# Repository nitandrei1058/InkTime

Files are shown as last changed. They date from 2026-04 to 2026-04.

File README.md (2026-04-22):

# InkTime - Smartwatch Open Source

## Diagrama Bloc

```mermaid
graph TD
    subgraph Power Management
        J4[USB-C Connector] -->|VBUS| D3[USBLC6-2SC6Y ESD]
        D3 --> IC1[BQ25180 LiPo Charger]
        BATT[LiPo Battery 250mAh] <--> IC1
        BATT --> U3[MAX17048 Fuel Gauge]
        IC1 -->|VSYS| IC9[RT6160A DC-DC Buck-Boost]
        IC9 -->|3.3V| VDD_SYS[System 3.3V]
    end

    subgraph Microcontroller
        U1[nRF52840 SoC]
        VDD_SYS --> U1
        U1 <-->|SWD| J2[TC2030 Debug]
        U1 <-->|RF| ANT[2.4GHz Antenna]
    end

    subgraph Peripherals
        U1 -->|I2C| IC3[BMA421 IMU]
        U1 -->|I2C| U3
        U1 -->|I2C| IC2[DRV2605L Haptic]
        U1 -->|I2C| IC1
        IC2 --> MOTOR[Vibration Motor]
        U1 -->|SPI + GPIO| J1["EPD Display 1.54 inch"]
        U1 -->|GPIO| BTN[3x Tactile Buttons]
    end
```

## Bill of Materials (BOM)

| Referință | Componentă | Valoare / Pachet | Datasheet | Link JLCParts / Procurare |
|:---|:---|:---|:---|:---|
| **U1** | Nordic nRF52840 | nRF52840-QIAA (QFN-73) | [Datasheet](https://infocenter.nordicsemi.com/pdf/nRF52840_PS_v1.7.pdf) | [C190794](https://jlcpcb.com/partdetail/NordicSemiconductor-nRF52840QIAA/C190794) |
| **IC1** | TI BQ25180 | LiPo Charger (DSBGA-8) | [Datasheet](https://www.ti.com/lit/ds/symlink/bq25180.pdf) | [C3682423](https://jlcpcb.com/partdetail/TexasInstruments-BQ25180YBGR/C3682423) |
| **IC9** | Richtek RT6160A | DC-DC Buck-Boost 3.3V | [Datasheet](https://www.richtek.com/assets/product_file/RT6160A/DS6160A-00.pdf) | [C7065276](https://jlcpcb.com/partdetail/RichtekTech-RT6160AWSC/C7065276) |
| **U3** | Analog MAX17048 | Fuel Gauge (TDFN-8) | [Datasheet](https://www.analog.com/media/en/technical-documentation/data-sheets/MAX17048-MAX17049.pdf) | [C2682616](https://jlcpcb.com/partdetail/2777647-MAX17048GT10/C2682616) |
| **IC3** | Bosch BMA421 | Accelerometru (LGA-12) | [Datasheet](https://www.bosch-sensortec.com/media/boschsensortec/downloads/datasheets/bst-bma423-ds000.pdf) | [C5242966](https://jlcpcb.com/partdetail/BoschSensortec-BMA423/C189517) |
| **IC2** | TI DRV2605L | Haptic Driver (DSBGA) | [Datasheet](https://www.ti.com/lit/ds/symlink/drv2605.pdf) | [C527464](https://jlcpcb.com/partdetail/TexasInstruments-DRV2605YZFR/C81079) |
| **D3** | ST USBLC6-2SC6Y | USB ESD (SOT-23-6) | [Datasheet](https://www.st.com/resource/en/datasheet/usblc6-2.pdf) | [C2969755](https://jlcpcb.com/partdetail/STMicroelectronics-USBLC62SC6Y/C2969755) |
| **J4** | KH-TYPE-C-16P | USB-C 16-pin | - | [C709357](https://jlcpcb.com/partdetail/Shenzhen_KinghelmElec-KH_TYPE_C16P/C709357) |
| **J1** | Molex 503480-2400 | FPC 24-pin pt EPD | [Datasheet](https://www.molex.com/en-us/products/part-detail/503480-2400) | [C122434](https://jlcpcb.com/partdetail/MOLEX-5034802400/C122434) |
| **J2** | TC2030-IDC | SWD Tag-Connect | [Datasheet](https://www.tag-connect.com/product/tc2030-idc-nl) | - |
| **ANT1**| Johanson 2450AT18 | Antenă 2.4GHz | [Datasheet](https://www.johansontechnology.com/datasheets/2450AT18B100E/2450AT18B100E.pdf)| [C2917717](https://jlcpcb.com/partdetail/JohansonDielectrics-2450AT18B100E/C2917717) |
| **X1** | 32MHz | Oscilator HFXO | - | [C383840](https://jlcpcb.com/partdetail/357112-X201632MMB4SI/C383840) |
| **X2** | 32.768kHz | Oscilator LFXO | - | [C32346](https://jlcpcb.com/partdetail/SeikoEpson-Q13FC13500004/C32346) |
| **SW1-3**| EVP-AKE31A | Butoane tactile | [Datasheet](https://industrial.panasonic.com/cdbs/www-data/pdf/ATV0000/ATV0000CE5.pdf) | [C136814](https://jlcpcb.com/parts/componentSearch?searchTxt=EVP-AKE31A) |
| **Q1** | DMG2305UX / AO3401A| P-MOSFET EPD Power | [Datasheet](https://www.diodes.com/assets/Datasheets/DMG2305UX.pdf) | [C15127](https://jlcpcb.com/partdetail/Alpha_OmegaSemicon-AO3401A/C15127) |
| **Q3** | SI1308EDL | N-MOSFET EPD Boost | [Datasheet](https://www.vishay.com/docs/73217/si1308edl.pdf) | [C469327](https://jlcpcb.com/partdetail/VishayIntertech-SI1308EDL_T1GE3/C469327) |
| **-** | AKYGA LP502030 | Baterie LiPo 3.7V / 250mAh | [Datasheet](https://www.tme.eu/Document/b9e12bf26ad0ba929a22ab5d58f022cd/AKY0106.pdf) | Extern |
| **-** | Waveshare 1.54" | Display EPD 200x200 | [Datasheet](https://www.tme.eu/Document/0ca57a8ffbcd57b5bca53252eb9d6ec3/WSH-12561.pdf) | Extern |
| **-** | FIT0774 | Motor Vibrații 10x2.7mm | - | Extern |

*(Notă: Inductoarele de boost/RF/Buck, diodele MBR0530, rezistențele și condensatorii SMD se regăsesc enumerate complet în fișierul `.bom` și `.csv` atașate la proiect).*

## Funcționalitate Hardware

Arhitectura InkTime a fost gândită în primul rând pentru **gestionarea eficientă a consumului de energie** și miniaturizare. Am folosit un proces de asamblare pe o singură parte a plăcii (TOP) și o grosime a PCB-ului de **1mm**.

### 1. Modulul de Procesare & RF
Microcontrollerul central este **Nordic nRF52840 (QFN-73)**, ideal datorită capabilităților extinse, integrarea Bluetooth 5 Low Energy și consum redus. Placa include o antenă de 2.4GHz tip chip (Johanson) conectată la o rețea de adaptare a impedanței formată din condensatori și inductoare minime. Zona de sub antenă respectă o restricție strictă (keepout pe planul de masă) pe ambele straturi pentru a asigura transmisia RF adecvată. Mufa USB-C folosește direct controllerul USB nativ din MCU și este protejată contra descărcărilor electrostatice (ESD) prin componenta D3 (USBLC6).

### 2. Power Management & Încărcare (PMIC)
Sistemul utilizează următoarele blocuri:
*   **BQ25180 (IC1):** Se ocupă de încărcarea celulei LiPo din VBUS (USB-C). Permite configurare hardware via I2C și generează rail-ul de sistem VSYS.
*   **RT6160A (IC9):** Regulator Buck-Boost sincron ce preia tensiunea VSYS/Baterie (3.0V – 4.2V) și oferă un `3.3V` curat pe întreg sistemul (VDD_SYS). E esențial pentru menținerea unei tensiuni stabile când bateria scade sub 3.3V.
*   **MAX17048 (U3):** Fuel Gauge dedicat. Acesta măsoară tensiunea bateriei (State of Charge) și raportează statusul prin I2C. Acest lucru ajută nRF52840 să rămână în deep sleep mai mult timp, omițând folosirea unui ADC intern. Emite alertă fizică prin pinul ALRT.

### 3. Display E-Paper (1.54")
Afișajul comunică cu MCU via **SPI**. Beneficiul E-Paper este consumul zero de curent între refresh-uri. Pentru a tăia chiar și curentul "standby" al panoului, placa conține un circuit separat de gating (Q1, un P-MOSFET) activat prin pinul `EPD_PWR`. De asemenea, pentru că afișajul EPD necesită tensiuni ridicate de refresh, există un circuit boost integrat (Q3 N-MOSFET, bobina de 68uH) pe care MCU îl activează înainte de transmiterea de date SPI.

### 4. Senzori & UI
*   **Accelerometru BMA421 (IC3):** Folosit la monitorizarea numărului de pași (pedometru intern) și detectarea de tilt/mișcare a încheieturii. Comunică I2C și folosește pinii `INT1` și `INT2` pentru a trezi SoC-ul din deep sleep prin intrerupere pe tranzitie (hardware wake).
*   **Feedback Haptic (DRV2605L - IC2):** Rulează pattern-uri haptice dintr-o memorie ROM internă, reducând timpii de procesare ai MCU-ului. Gestionează un motor ERM mic (FIT0774). Poate fi oprit complet din funcționare prin pinul `EN`.
*   **3 Butoane Tactile:** Acționează cu rolurile de Up (`SW_UP`), Enter/Escape (`SW_ENT`) și Down (`SW_DN`). Sunt butoane active-low ce declanșează întreruperi cu rezistențe de pull-up activate din interiorul MCU.

### Calcule Estimative de Consum (Power Budget)
*   **Deep Sleep** (Afișaj static, radio inactiv, RTC + IMU active): **~10 - 20 µA**
*   **BLE Activ** (RX/TX Notificări): **~3 - 5 mA** (burst-uri foarte scurte)
*   **Afișaj E-Paper Refresh** (1 minut): **~10 - 15 mA** (pe durata de ~1s - 2s a refresh-ului parțial)
*   **Alertă Haptică:** **~50 - 100 mA** (timp de fracțiuni de secundă)
Presupunând un profil tipic de ~50 de notificări/zi și refresh o dată pe minut, o baterie de 250mAh ar trebui să dureze cu lejeritate **cel puțin 30 de zile**.

## Mapare Pini nRF52840

Alegerea pinilor a urmărit scurtarea și degajarea traseelor critice de RF, precum și o evadare eficientă din footprint-ul capsulei nRF52840 pe un singur strat de rutare utilitară. 

| Semnal | Pin nRF | Funcție | Detalii & Justificare |
| :--- | :---: | :--- | :--- |
| **I2C_SDA** | `P0.06` | Date I2C | Linii partajate între BMA421, MAX17048, DRV2605 și BQ25180. |
| **I2C_SCL** | `P0.07` | Clock I2C | Linii cu rezistențe pull-up la 3.3V (VDD_SYS). |
| **SPI_MOSI**| `P0.03` | SPI TX | Către J1 (EPD). Folosite pentru trimitere buffer ecran. |
| **SPI_SCK** | `P0.02` | SPI Clock| Către J1 (EPD). |
| **SPI_CS** | `P0.05` | SPI Chip Select | Selecție device SPI (Afișaj). |
| **EPD_DC** | `P0.15` | Data / Command | Controlează modul în care display-ul interpretează payload-ul SPI. |
| **EPD_RST** | `P0.16` | Reset EPD | Resetează starea hardware a panoului E-Paper. |
| **EPD_BUSY**| `P0.17` | BUSY indicator | Pin citit de MCU pentru a pune MCU în delay cât EPD randează frame-ul. |
| **EPD_PWR** | `P1.01` | Enable E-Paper | Deschide tranzistorul MOSFET Q1 pentru a tăia / da power panoului. |
| **IMU_INT1**| `P0.08` | Intrerupere 1 | Primește semnal wake de la accelerometru (gest). |
| **IMU_INT2**| `P1.08` | Intrerupere 2 | Primește semnal pedometru/dublu tap. |
| **PMIC_INT**| `P0.11` | Intrerupere Încărcare| Semnalizează finalizarea încărcării USB. |
| **BAT_ALRT**| `P0.10` | Alertă Baterie | Întrerupere de la fuel gauge la prag de "Low Battery". |
| **HAP_EN** | `P0.12` | DRV2605 Enable | Trezește din deep sleep/shutdown haptic driver-ul IC2. |
| **SW_UP** | `P0.13` | Buton UP | Active Low. |
| **SW_DN** | `P0.14` | Buton DOWN | Active Low. |
| **SW_ENT** | `P1.00` | Buton ENTER | Active Low. |
| **USB_D+** | `P0.20` | USB Data Pozitiv | Rutate direct către protecția ESD și portul J4 (USB nativ în nRF). |
| **USB_D-** | `P0.22` | USB Data Negativ | Rutate direct către protecția ESD și portul J4. |

*Pinii de programare `SWDIO` și `SWDCLK` sunt trași strict la pogo-header-ul Tag-Connect J2 pentru debug.*

## Constrângeri Respectate & Design Log
*   **Plasamentul 100% TOP:** Placa a fost rutată cu absolut toate componentele plasate exclusiv pe fața de TOP. Acest lucru garantează o grosime asamblată cât mai subțire (având spatele PCB-ului liber pentru lipirea fixă a bateriei), menținându-se într-o grosime maximă de **1mm** a PCB-ului.
*   **Erori DRC Asumate (Mecanic):** Mufa USB-C (J4) și cele 3 butoane tactile au fost amplasate strategic pentru a se potrivi exact cu decupajele din carcasa smartwatch-ului. Această poziționare generează erori de "Dimension" / "Clearance" la marginea plăcii în DRC, pe care mi le-am asumat.
*   **Erori DRC Asumate (Via in Pad):** Datorită densității pachetului aQFN73 al nRF52840, evadarea tuturor semnalelor pe un număr limitat de straturi a necesitat utilizarea de vias direct în pad-uri ("drill in pad") pentru pinii altfel inaccesibili. Erorile DRC rezultate din această tehnică de rutare sunt asumate.
*   **Cerințe layout RF:** Pentru antena 2450AT18 s-a menținut decupajul recomandat pe toate planurile de masă, interzicând ruta semnalelor de date/putere sub zona antenei pentru a optimiza eficiența și a reduce EMI.

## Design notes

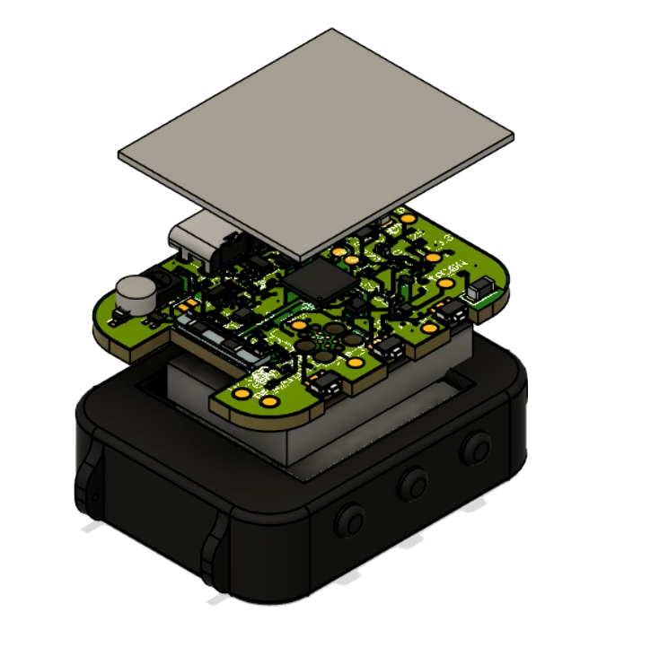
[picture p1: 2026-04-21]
Images/image.png

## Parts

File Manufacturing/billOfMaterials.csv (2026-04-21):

Reference Designators | Quantity | Description | Package | Value | Manufacturer | Manufacturer Part Number | Vendor | Vendor Part Number | Top/Bottom | ARROW_PART_NUMBER | ARROW_PRICE-STOCK | AVAILABILITY | CHECK_PRICES | COPYRIGHT | DESCRIPTION | JLCPCB | MANUFACTURER_NAME | MANUFACTURER_PART_NUMBER | MF | MFR_NAME | MOUSER_PART_NUMBER | MOUSER_PRICE-STOCK | MP | PACKAGE | POPULARITY | PRICE | PROD_ID | PURCHASE-URL | SNAPEDA_LINK | TP_SIGNAL_NAME
 | 1 | Board | Board
ANT1 | 1 | Antennas 2.45GHz ANTENNA | 2450AT18B100E_ANTC3216X140N | 2450AT18B100E |  |  |  |  | Top | 2450AT18B100E | https://www.arrow.com/en/products/2450at18b100e/johanson-dielectrics?utm_currency=USD&region=nac |  |  |  | Antennas 2.45GHz ANTENNA |  | JOHANSON TECHNOLOGY | 2450AT18B100E |  |  | 609-2450AT18B100E | https://www.mouser.co.uk/ProductDetail/Johanson-Technology/2450AT18B100E?qs=yCnrNFeXz%252Bh5MFsFIXGZGA%3D%3D
C1, C2, C17, C18 | 4 | Generic chip capacitor | NORDIC_NRF_3_RESC0201_L | 12pF |  |  |  |  | Top
C1-EP-DR, C24, C39 | 3 | Generic chip capacitor | NORDIC_NRF_3_RESC0402_L | 10uF |  |  |  |  | Top
C2-EP-DR | 1 | Generic chip capacitor | NORDIC_NRF_3_RESC0402_L | 4.7uF/25V |  |  |  |  | Top
C3, C4 | 2 | Generic chip capacitor | NORDIC_NRF_3_RESC0201_L | 1pF |  |  |  |  | Top
C5, C7, C8, C19 | 4 | Generic chip capacitor | NORDIC_NRF_3_RESC0201_L | 100nF |  |  |  |  | Top
C6, C14, C20, C21, C43 | 5 | Generic chip capacitor | NORDIC_NRF_3_RESC0402_L | 4.7uF |  |  |  |  | Top
C9 | 1 | Generic chip capacitor | NORDIC_NRF_3_RESC0201_L | 820pF |  |  |  |  | Top
C10, C13, C22 | 3 | Generic chip capacitor | NORDIC_NRF_3_RESC0201_L | N.C |  |  |  |  | Top
C11, C12 | 2 | Generic chip capacitor | NORDIC_NRF_3_RESC0201_L | 100pF |  |  |  |  | Top
C15 | 1 | Generic chip capacitor | NORDIC_NRF_3_RESC0402_L | 1.0uF |  |  |  |  | Top
C16 | 1 | Generic chip capacitor | NORDIC_NRF_3_RESC0201_L | 47nF |  |  |  |  | Top
C23, C27, C34, C42 | 4 | Check availability | GRM011R60J152KE01L_2_CAPC0201X13N | 0.1uF |  |  |  |  | Top |  |  | In Stock | https://www.snapeda.com/parts/GRM011R60J152KE01L/Murata/view-part/?ref=eda |  | SMD Capacitor X5R(EIA) with Capacitance: 1500pF Tol. 10%. Rated Voltage: 6.3Vdc |  |  |  | Murata |  |  |  | GRM011R60J152KE01L | 0201 Murata |  | None |  |  | https://www.snapeda.com/parts/GRM011R60J152KE01L/Murata/view-part/?ref=snap
C25, C33 | 2 | Generic chip capacitor | NORDIC_NRF_3_RESC0402_L | 22uF |  |  |  |  | Top
C29, C30, C31, C32, C37, C38 | 6 | Check availability | GRM011R60J152KE01L_2_CAPC0201X13N | 1uF |  |  |  |  | Top |  |  | In Stock | https://www.snapeda.com/parts/GRM011R60J152KE01L/Murata/view-part/?ref=eda |  | SMD Capacitor X5R(EIA) with Capacitance: 1500pF Tol. 10%. Rated Voltage: 6.3Vdc |  |  |  | Murata |  |  |  | GRM011R60J152KE01L | 0201 Murata |  | None |  |  | https://www.snapeda.com/parts/GRM011R60J152KE01L/Murata/view-part/?ref=snap
D2, D5, DE_PUS | 3 | ON SEMICONDUCTOR - MBR0530 - DIODE, SCHOTTKY, 0.5A, 30V, SOD-123 | ESP32_C6_LIBRARY_5_SOD3716X135N | MBR0530 |  |  |  |  | Top |  |  | In Stock | https://www.snapeda.com/parts/MBR0530/Onsemi/view-part/?ref=eda |  | Diode Schottky 30 V 500mA Surface Mount SOD-123 |  |  |  | ON Semiconductor |  |  |  | MBR0530 | SOD-123-2 ON Semiconductor |  | None |  | https://www.snapeda.com/api/url_track_click_mouser/?unipart_id=179458&manufacturer=ON Semiconductor&part_name=MBR0530&search_term=None | https://www.snapeda.com/parts/MBR0530/Onsemi/view-part/?ref=snap
D3 | 1 | Low Cap. ESD Protection Auto SOT-23-6 STMicroelectronics USBLC6-2SC6Y, Dual Uni-Directional TVS Diode Array, 6-Pin SOT-23 | ESP32_C6_LIBRARY_3_SOT95P280X145-6N | USBLC6-2SC6Y |  |  |  |  | Top |  |  | In Stock | https://www.snapeda.com/parts/USBLC6-2SC6Y/STMicroelectronics/view-part/?ref=eda |  | 17V Clamp 5A (8/20µs) Ipp Tvs Diode Surface Mount SOT-23-6 |  |  |  | STMicroelectronics |  |  |  | USBLC6-2SC6Y | SOT-23-6 STMicroelectronics |  | None |  |  | https://www.snapeda.com/parts/USBLC6-2SC6Y/STMicroelectronics/view-part/?ref=snap
EPD_C1, EPD_C2, EPD_C6, EPD_C7, EPD_C8, EPD_C9, EPD_C10, EPD_C11, EPD_C12 | 9 | Generic chip capacitor | NORDIC_NRF_3_RESC0402_L | 1uF/50V |  |  |  |  | Top
EPD_C5 | 1 | Generic chip capacitor | NORDIC_NRF_3_RESC0402_L | 0.1uF/50V |  |  |  |  | Top
IC1 | 1 | Charger IC Lithium Ion/Polymer, Lithium Iron Phosphate 8-DSBGA (1.6x1.1) | BQ25180YBGR_BGA8C40P2X4_100X155X50 | BQ25180YBGR |  |  |  |  | Top | BQ25180YBGR | https://www.arrow.com/en/products/bq25180ybgr/texas-instruments?utm_currency=USD&region=nac |  |  |  | Charger IC Lithium Ion/Polymer, Lithium Iron Phosphate 8-DSBGA (1.6x1.1) |  | Texas Instruments | BQ25180YBGR |  |  | 595-BQ25180YBGR | https://www.mouser.co.uk/ProductDetail/Texas-Instruments/BQ25180YBGR?qs=doiCPypUmgEWjAK%252BJAX6Tw%3D%3D
IC2 | 1 | Haptic Driver for ERM/LRA with Built-In Library and Smart Loop Architecture | DRV2605YZFR_BGA9C50P3X3_144X144X62 | DRV2605YZFR |  |  |  |  | Top | DRV2605YZFR | https://www.arrow.com/en/products/drv2605yzfr/texas-instruments?region=nac |  |  |  | Haptic Driver for ERM/LRA with Built-In Library and Smart Loop Architecture |  | Texas Instruments | DRV2605YZFR
IC3 | 1 | Accelerometers Triaxial low-g 12bit Acceleration Sensor | BMA423_BMA423 | BMA421 |  |  |  |  | Top | BMA423 | https://www.arrow.com/en/products/bma423/bosch |  |  |  | Accelerometers Triaxial low-g 12bit Acceleration Sensor |  | BOSCH | BMA423 |  |  | 262-BMA423 | https://www.mouser.co.uk/ProductDetail/Bosch-Sensortec/BMA423?qs=HXFqYaX1Q2xC%252BSgeGoX3mg%3D%3D
IC9 | 1 | Buck-Boost Regulator Positive Output Step-Up/Step-Down I2C DC-DC Controller IC 15-WL-CSP (BSC) (1.4x2.3) | RT6160AWSC_BGA15C40P3X5_140X230X60 | RT6160AWSC |  |  |  |  | Top |  |  |  |  |  | Buck-Boost Regulator Positive Output Step-Up/Step-Down I2C DC-DC Controller IC 15-WL-CSP (BSC) (1.4x2.3) |  | RICHTEK | RT6160AWSC |  |  | 835-RT6160AWSC | https://www.mouser.co.uk/ProductDetail/Richtek/RT6160AWSC?qs=amGC7iS6iy%2FLd9PSoixZXQ%3D%3D
J1 | 1 | FFC & FPC Connectors 0.5mm FPC RA SMT Dual Contact 24Ckt | 503480-2400_5034802400 | 503480-2400 |  |  |  |  | Top |  |  |  |  |  | FFC & FPC Connectors 0.5mm FPC RA SMT Dual Contact 24Ckt |  | Molex | 503480-2400 |  |  | 538-503480-2400 | https://www.mouser.co.uk/ProductDetail/Molex/503480-2400?qs=OAhjpuo3Vu7efIoxFh9AOw%3D%3D
J2 | 1 | CABLE ADAPTER 6 POS | TC2030-IDC_TC2030IDC | TC2030-IDC |  |  |  |  | Top |  |  |  |  |  | CABLE ADAPTER 6 POS |  | Tag Connect | TC2030-IDC
J4 | 1 | Check availability | KH-TYPE-C-16P_KINGHELM_KH-TYPE-C-16P | KH-TYPE-C-16P |  |  |  |  | Top |  |  | Not in stock | https://www.snapeda.com/parts/KH-TYPE-C-16P/Kinghelm/view-part/?ref=eda |  |  |  |  |  | kinghelm |  |  |  | KH-TYPE-C-16P | None |  | None |  |  | https://www.snapeda.com/parts/KH-TYPE-C-16P/Kinghelm/view-part/?ref=snap
L1 | 1 | Generic chip inductor | NORDIC_NRF_2_RESC0402_L | 3.9nH |  |  |  |  | Top
L2 | 1 | Generic chip inductor | NORDIC_NRF_2_RESC0603_L | 10uH |  |  |  |  | Top
L3 | 1 | Generic chip inductor | NORDIC_NRF_2_RESC0201_L | 15nH |  |  |  |  | Top
L5 | 1 |  | ESP32_C6_LIBRARY_2_IND_4828-WE-TPC_WRE | 68uH |  |  |  |  | Top |  |  |  |  | Copyright (C) 2024 Ultra Librarian. All rights reserved. |  |  |  | 744043680 |  | Wurth Electronics
L7 | 1 | SMD / SMT Inductors (Coils), L=0.47?H, L x W x T : | MLP2016SR47MT0S1_INDC2016X100N | FTC252012SR47MBCA |  |  |  |  | Top |  |  |  |  |  | SMD / SMT Inductors (Coils), L=0.47?H, L x W x T : | https://jlcpcb.com/partdetail/6763488-FTC252012SR47MBCA/C5832368 | TDK | FTC252012SR47MBCA
Q1 | 1 | P-channel MOSFETs | ESP32_WROVER_SPARKFUN-DISCRETESEMI_SOT23-3 | 20V/4.2A/52mΩ/1.4W |  |  |  |  | Top |  |  |  |  |  |  |  |  |  |  |  |  |  |  |  |  |  | TRAN-14388
Q3 | 1 | MOSFET N-Ch 30V 1.5A TrenchFET SC70 Vishay Si1308EDL-T1-GE3 N-channel MOSFET Transistor, 1.5 A, 30 V, 3-Pin SC-70 | SOT65P210X110-3N | SI1308EDL-T1-GE3 |  |  |  |  | Top |  |  | In Stock | https://www.snapeda.com/parts/SI1308EDL-T1-GE3/Vishay+Siliconix/view-part/?ref=eda |  | Si1308EDL-T1-GE3 N-channel MOSFET Transistor, 1.5 A, 30 V, 3-Pin SC-70 | Siliconix / Vishay SI1308EDL-T1-GE3 |  |  |  | Vishay Siliconix |  |  |  | SI1308EDL-T1-GE3 | SOT-323 Vishay Semiconductor |  | None |  | https://www.snapeda.com/api/url_track_click_mouser/?unipart_id=274603&manufacturer=Vishay Siliconix&part_name=SI1308EDL-T1-GE3&search_term=None | https://www.snapeda.com/parts/SI1308EDL-T1-GE3/Vishay+Siliconix/view-part/?ref=snap
R_PWR_EPD, R2_EP_DR, R9 | 3 | 7.68k 0201 Thin Film Surface Mount Fixed Resistor +/-0.5% 0.031W CPF0201D7K68C1 | CPF0201D7K68C1_0201 | 10K |  |  |  |  | Top
R_TYPE_SEL | 1 | 7.68k 0201 Thin Film Surface Mount Fixed Resistor +/-0.5% 0.031W CPF0201D7K68C1 | CPF0201D7K68C1_0201 | 2.2 |  |  |  |  | Top
R1_EP_DR | 1 | 7.68k 0201 Thin Film Surface Mount Fixed Resistor +/-0.5% 0.031W CPF0201D7K68C1 | CPF0201D7K68C1_0201 | 0.47 |  |  |  |  | Top
R1_USB, R2_USB | 2 | 7.68k 0201 Thin Film Surface Mount Fixed Resistor +/-0.5% 0.031W CPF0201D7K68C1 | CPF0201D7K68C1_0201 | 5K1 |  |  |  |  | Top
R2, R3, R4 | 3 | 7.68k 0201 Thin Film Surface Mount Fixed Resistor +/-0.5% 0.031W CPF0201D7K68C1 | CPF0201D7K68C1_0201 | 0 |  |  |  |  | Top
R5, R7, R8 | 3 | 7.68k 0201 Thin Film Surface Mount Fixed Resistor +/-0.5% 0.031W CPF0201D7K68C1 | CPF0201D7K68C1_0201 | 10k |  |  |  |  | Top
R17, R18 | 2 | 7.68k 0201 Thin Film Surface Mount Fixed Resistor +/-0.5% 0.031W CPF0201D7K68C1 | CPF0201D7K68C1_0201 | 3K3 |  |  |  |  | Top
SJ1 | 1 | SMD solder JUMPER | ESP32_C6_LIBRARY_7_JUMPER_SJ | 0 |  |  |  |  | Top |  |  |  |  |  |  |  |  |  |  |  |  |  |  |  | 3
SW_DN, SW_ENT, SW_UP | 3 |  | 2025-10-22_07-23-44_LIBRARY_SW_EVP-AKE31A_PAN | 2025-10-22_07-23-44_LIBRARY_EVP-AKE31ASW_EVP-AKE31A_PAN |  |  |  |  | Top |  |  |  |  | Copyright (C) 2025 Ultra Librarian. All rights reserved. |  |  | Panasonic | EVP-AKE31A
TP_3.3V, TP_3V3, TP_BAT_GND, TP_GND, TP_ON, TP_OP, TP_RESET, TP_SCL, TP_SDA, TP_SWDCLK, TP_SWDIO, TP_SWO, TP_VBAT, TP_VREG | 14 | Test pad | HECTOR_WATCH_1_TP20R | HECTOR_WATCH_1_TPTP20R |  |  |  |  | Top |  |  |  |  |  |  |  |  |  |  |  |  |  |  |  | 2
U1 | 1 | nRF52840 | NORDIC_NRF_4_AQFN50P700X700X85_HS-74N | NRF52840_QF |  |  |  |  | Top
U3 | 1 | Check availability | ESP32_C6_LIBRARY_SON50P200X200X80-9N | ESP32_C6_LIBRARY_MAX17048G+T10 |  |  |  |  | Top |  |  | In Stock | https://www.snapeda.com/parts/MAX17048G+T10/Analog+Devices/view-part/?ref=eda |  | 3µA 1-Cell/2-Cell Fuel Gauge with ModelGauge |  |  |  | Analog Devices |  |  |  | MAX17048G+T10 | TDFN-8 Maxim |  | None |  | https://www.snapeda.com/api/url_track_click_mouser/?unipart_id=329239&manufacturer=Analog Devices&part_name=MAX17048G+T10&search_term=None | https://www.snapeda.com/parts/MAX17048G+T10/Analog+Devices/view-part/?ref=snap
X1 | 1 |  | NORDIC_NRF_BT-XTAL_2016_N | 32MHz |  |  |  |  | Top
X2 | 1 |  | NORDIC_NRF_1_XTAL_3215_N | 32.768KHz |  |  |  |  | Top

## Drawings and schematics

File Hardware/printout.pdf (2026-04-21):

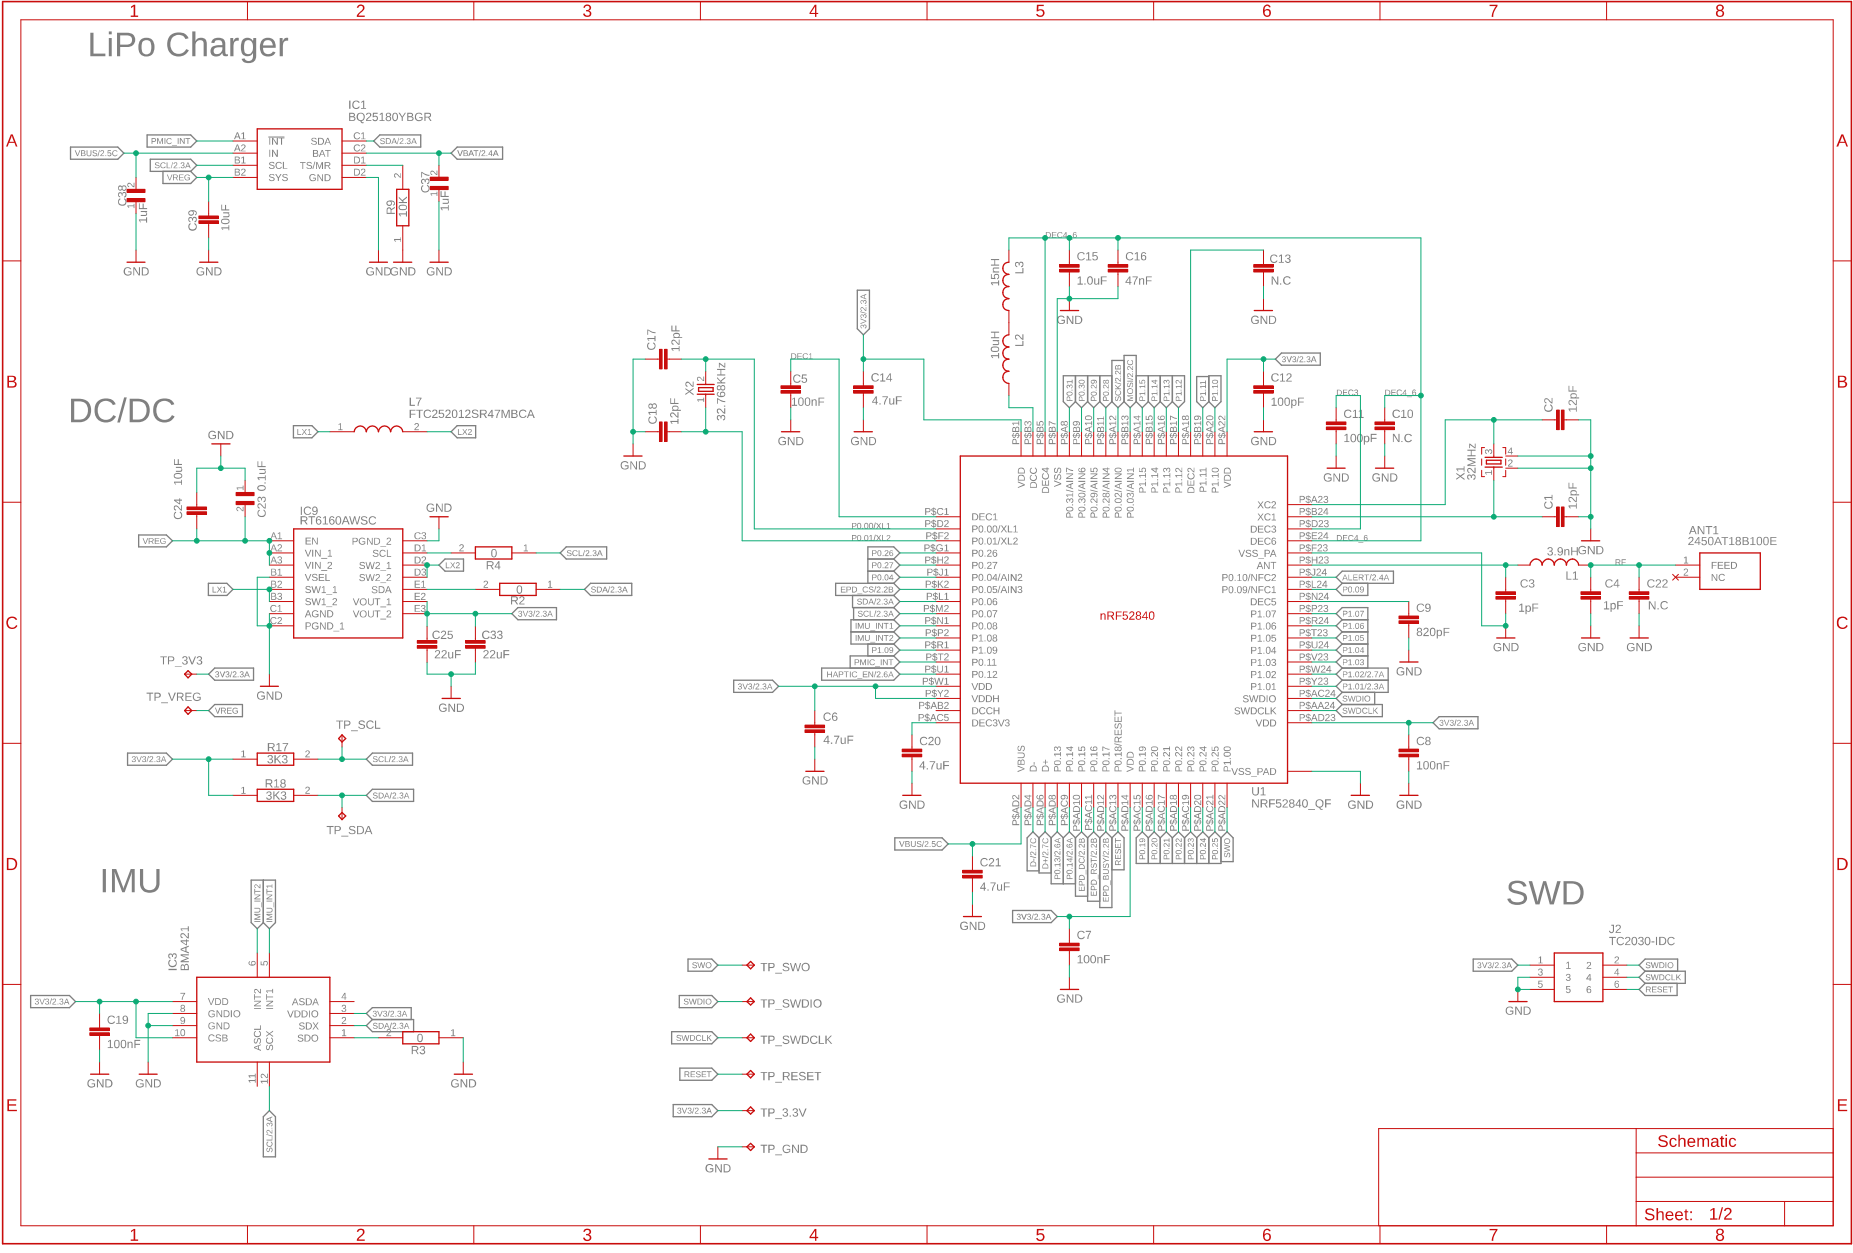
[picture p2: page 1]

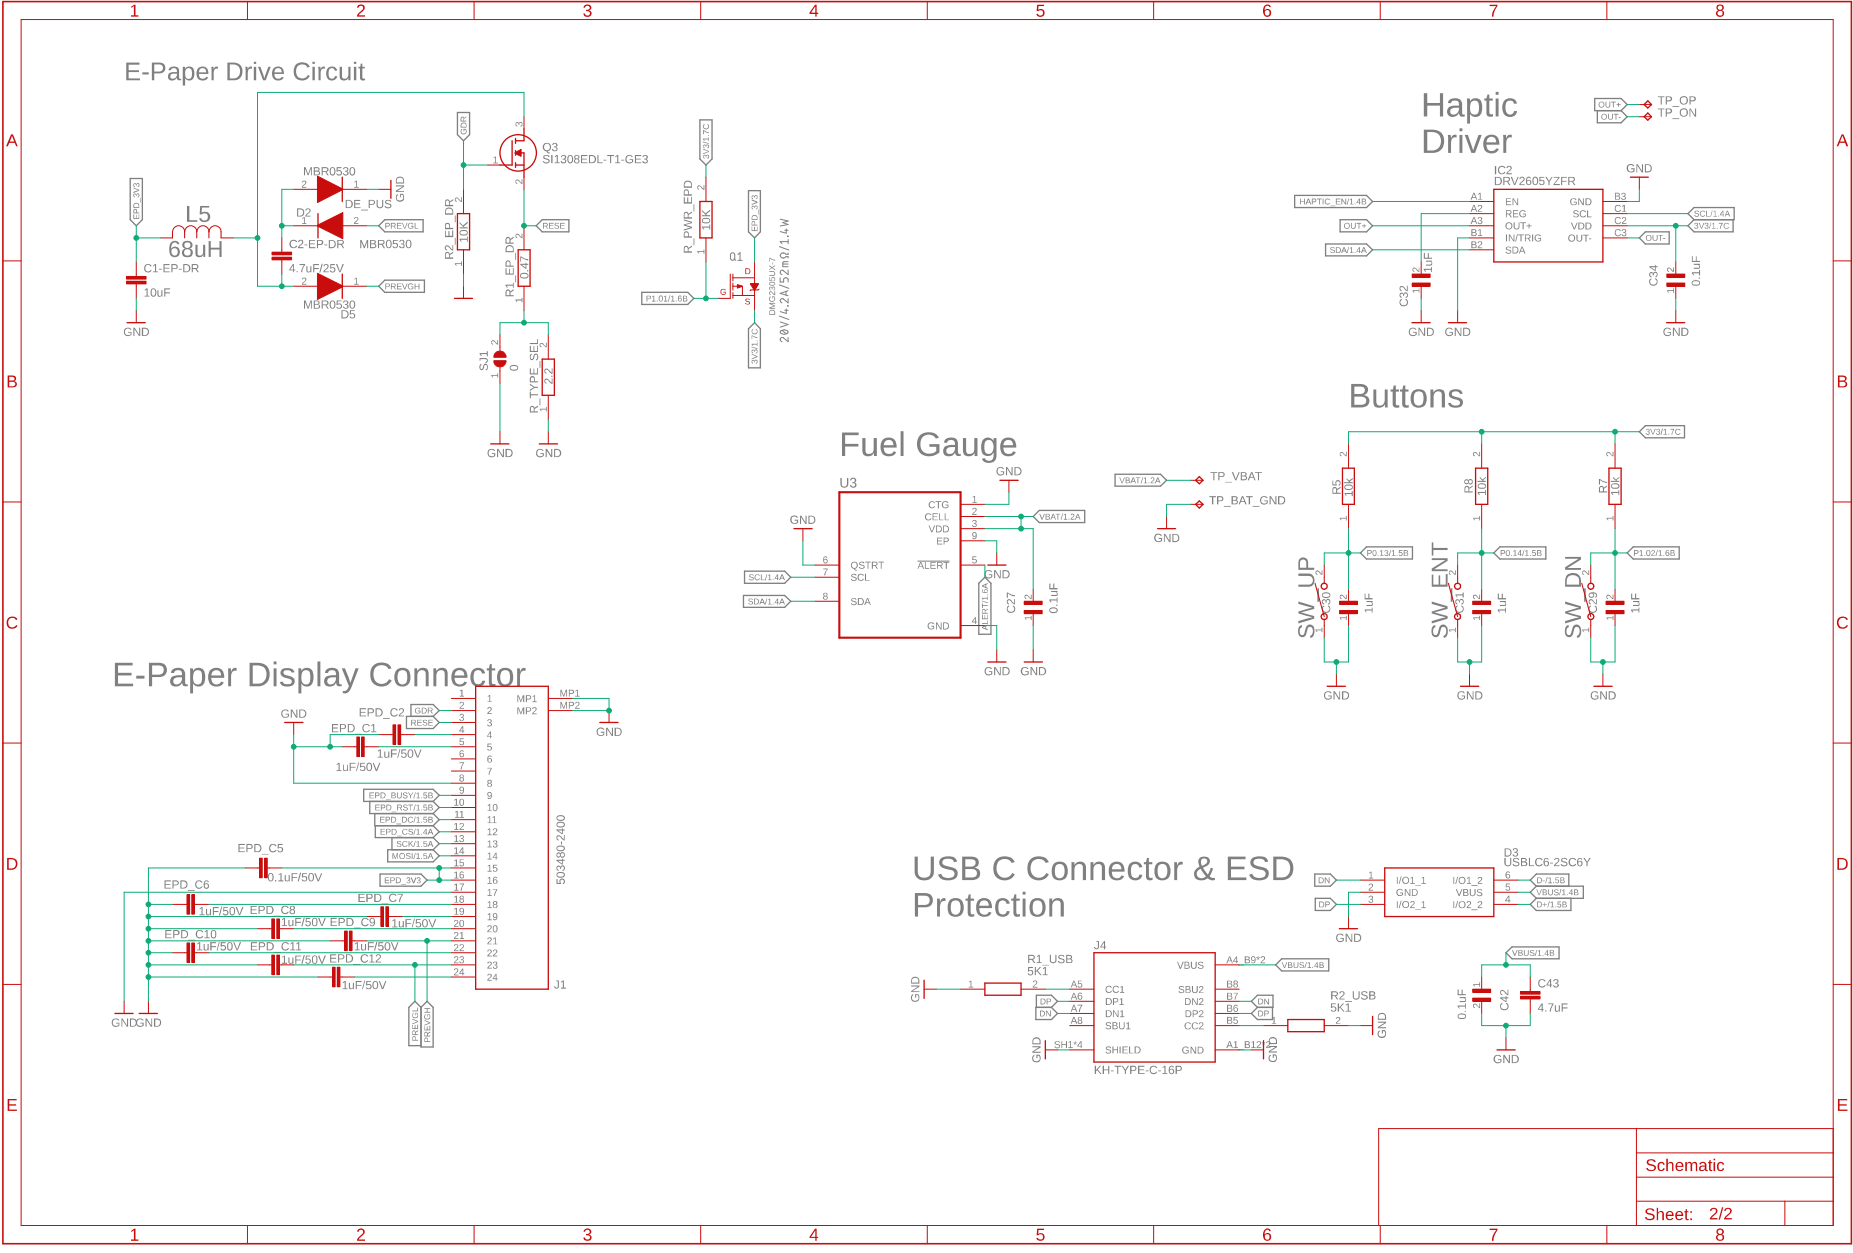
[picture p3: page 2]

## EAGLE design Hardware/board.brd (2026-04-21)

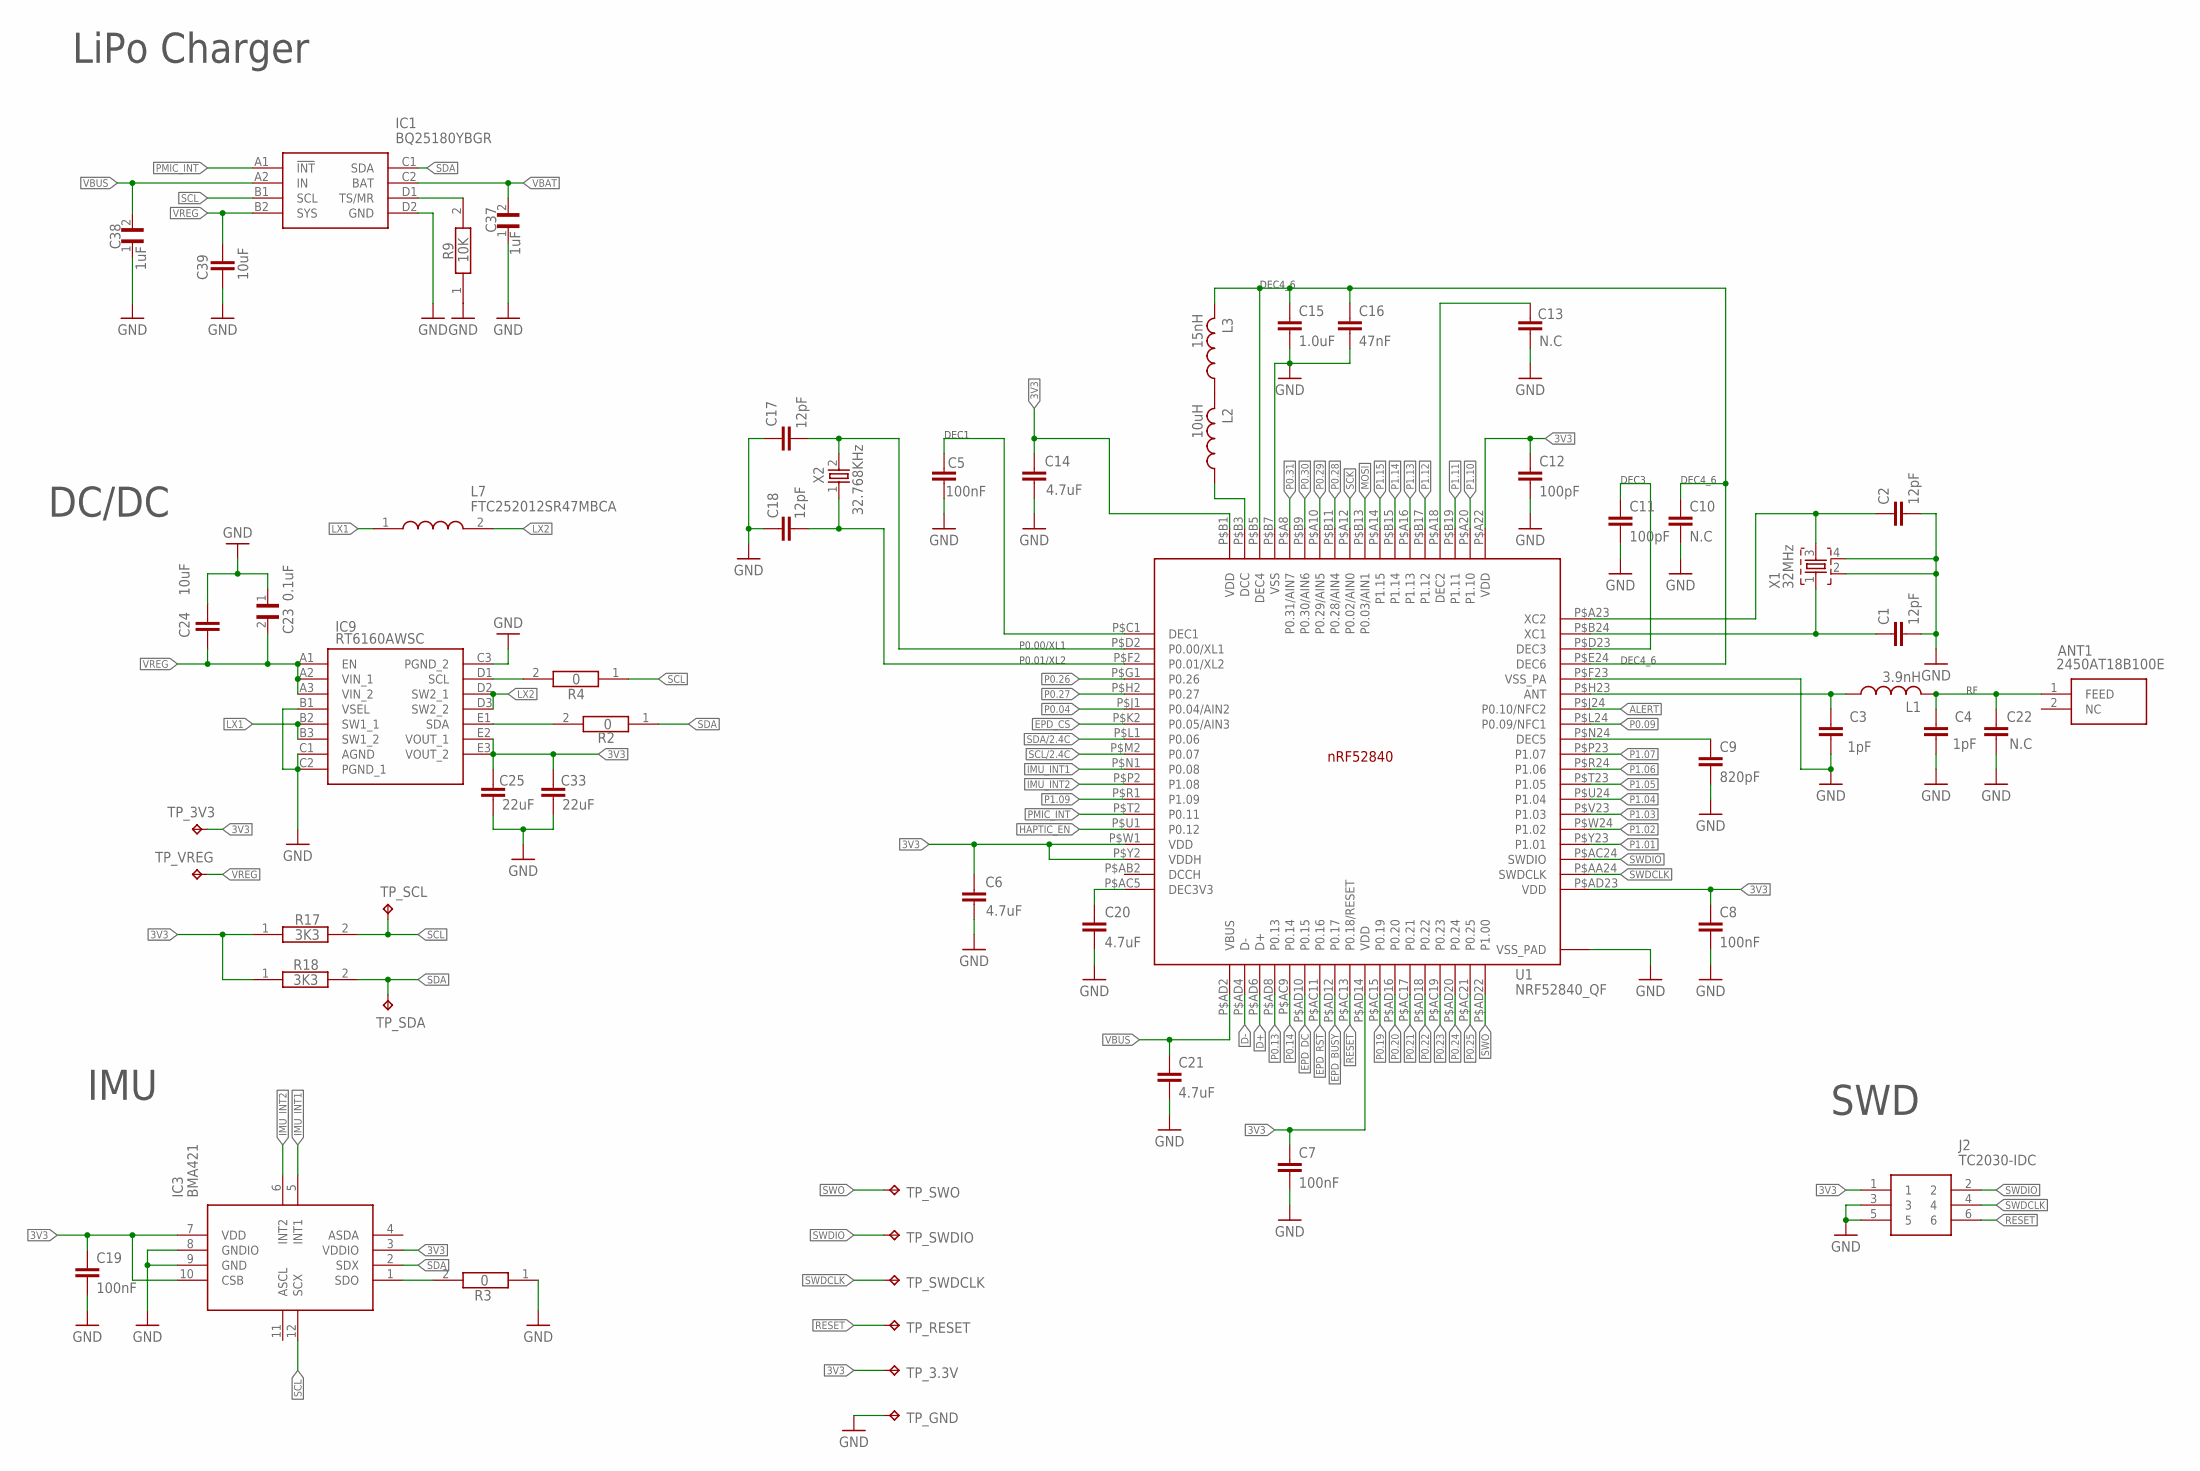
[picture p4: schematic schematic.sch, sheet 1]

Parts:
ANT1: 2450AT18B100E; 2450AT18B100E_ANTC3216X140N
C1, C2, C17, C18: 12pF; NORDIC_NRF_3_RESC0201_L
C3, C4: 1pF; NORDIC_NRF_3_RESC0201_L
C5, C7, C8, C19: 100nF; NORDIC_NRF_3_RESC0201_L
C6, C14, C20, C21: 4.7uF; NORDIC_NRF_3_RESC0402_L
C9: 820pF; NORDIC_NRF_3_RESC0201_L
C10, C13, C22: N.C; NORDIC_NRF_3_RESC0201_L
C11, C12: 100pF; NORDIC_NRF_3_RESC0201_L
C15: 1.0uF; NORDIC_NRF_3_RESC0402_L
C16: 47nF; NORDIC_NRF_3_RESC0201_L
C23: 0.1uF; GRM011R60J152KE01L_2_CAPC0201X13N
C24, C39: 10uF; NORDIC_NRF_3_RESC0402_L
C25, C33: 22uF; NORDIC_NRF_3_RESC0402_L
C37, C38: 1uF; GRM011R60J152KE01L_2_CAPC0201X13N
IC1: BQ25180YBGR; BQ25180YBGR_BGA8C40P2X4_100X155X50
IC3: BMA421; BMA423_BMA423
IC9: RT6160AWSC; RT6160AWSC_BGA15C40P3X5_140X230X60
J2: TC2030-IDC; TC2030-IDC_TC2030IDC
L1: 3.9nH; NORDIC_NRF_2_RESC0402_M
L2: 10uH; NORDIC_NRF_2_RESC0603_L
L3: 15nH; NORDIC_NRF_2_RESC0201_L
L7: FTC252012SR47MBCA; MLP2016SR47MT0S1_INDC2016X100N
R2, R3, R4: 0; CPF0201D7K68C1_0201
R9: 10K; CPF0201D7K68C1_0201
R17, R18: 3K3; CPF0201D7K68C1_0201
TP_3.3V, TP_3V3: HECTOR_WATCH_1_TPTP20R; HECTOR_WATCH_1_TP20R
TP_GND: HECTOR_WATCH_1_TPTP20R; HECTOR_WATCH_1_TP20R
TP_RESET: HECTOR_WATCH_1_TPTP20R; HECTOR_WATCH_1_TP20R
TP_SCL: HECTOR_WATCH_1_TPTP20R; HECTOR_WATCH_1_TP20R
TP_SDA: HECTOR_WATCH_1_TPTP20R; HECTOR_WATCH_1_TP20R
TP_SWDCLK: HECTOR_WATCH_1_TPTP20R; HECTOR_WATCH_1_TP20R
TP_SWDIO: HECTOR_WATCH_1_TPTP20R; HECTOR_WATCH_1_TP20R
TP_SWO: HECTOR_WATCH_1_TPTP20R; HECTOR_WATCH_1_TP20R
TP_VREG: HECTOR_WATCH_1_TPTP20R; HECTOR_WATCH_1_TP20R
U1: NRF52840_QF; NORDIC_NRF_4_AQFN50P700X700X85_HS-74N
X1: 32MHz; NORDIC_NRF_BT-XTAL_2016_N
X2: 32.768KHz; NORDIC_NRF_1_XTAL_3215_N

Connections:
3V3: C6.2, C7.1, C8.1, C12.1, C14.2, C19.1, C25.1, C33.1, IC3.3 (VDDIO), IC3.7 (VDD), IC3.10 (CSB), IC9.E2 (VOUT_1), IC9.E3 (VOUT_2), J2.1, R17.1, R18.1, TP_3.3V.TP, TP_3V3.TP, U1.P$A22 (VDD), U1.P$AD14 (VDD), U1.P$AD23 (VDD), U1.P$B1 (VDD), U1.P$W1 (VDD), U1.P$Y2 (VDDH); also elsewhere on the board
ALERT: U1.P$J24 (P0.10/NFC2); also elsewhere on the board
D+: U1.P$AD6 (D+); also elsewhere on the board
D-: U1.P$AD4 (D-); also elsewhere on the board
EPD_BUSY: U1.P$AD12 (P0.17); also elsewhere on the board
EPD_CS: U1.P$K2 (P0.05/AIN3); also elsewhere on the board
EPD_DC: U1.P$AD10 (P0.15); also elsewhere on the board
EPD_RST: U1.P$AC11 (P0.16); also elsewhere on the board
GND: C1.2, C2.2, C3.1, C4.1, C5.1, C6.1, C7.2, C8.2, C9.2, C10.2, C11.2, C12.2, C13.2, C14.1, C15.2, C16.2, C17.2, C18.2, C19.2, C20.1, C21.2, C22.1, C23.1, C24.1, C25.2, C33.2, C37.1, C38.1, C39.2, IC1.D2 (GND), IC3.8 (GNDIO), IC3.9 (GND), IC9.B1 (VSEL), IC9.C1 (AGND), IC9.C2 (PGND_1), IC9.C3 (PGND_2), J2.3, J2.5, R3.1, R9.1, TP_GND.TP, U1.P$74 (VSS_PAD), U1.P$75 (VSS_PAD), U1.P$76 (VSS_PAD), U1.P$77 (VSS_PAD), U1.P$78 (VSS_PAD), U1.P$79 (VSS_PAD), U1.P$80 (VSS_PAD), U1.P$81 (VSS_PAD), U1.P$82 (VSS_PAD), U1.P$83 (VSS_PAD), U1.P$84 (VSS_PAD), U1.P$85 (VSS_PAD), U1.P$86 (VSS_PAD), U1.P$87 (VSS_PAD), U1.P$88 (VSS_PAD), U1.P$89 (VSS_PAD), U1.P$90 (VSS_PAD), U1.P$B7 (VSS), U1.P$F23 (VSS_PA), X1.2, X1.4; also elsewhere on the board
HAPTIC_EN: U1.P$U1 (P0.12); also elsewhere on the board
IMU_INT1: IC3.5 (INT1), U1.P$N1 (P0.08)
IMU_INT2: IC3.6 (INT2), U1.P$P2 (P1.08)
LX1: IC9.B2 (SW1_1), IC9.B3 (SW1_2), L7.1
LX2: IC9.D2 (SW2_1), IC9.D3 (SW2_2), L7.2
MOSI: U1.P$B13 (P0.03/AIN1); also elsewhere on the board
unnamed: IC1.D1 (TS/MR), R9.2
unnamed: C9.1, U1.P$N24 (DEC5)
unnamed: C3.2, L1.1, U1.P$H23 (ANT)
unnamed: IC9.D1 (SCL), R4.2
unnamed: IC9.E1 (SDA), R2.2
unnamed: C20.2, U1.P$AC5 (DEC3V3)
unnamed: ANT1.1 (FEED), C4.2, C22.2, L1.2
unnamed: C1.1, U1.P$B24 (XC1), X1.1
unnamed: C2.1, U1.P$A23 (XC2), X1.3
unnamed: C11.1, U1.P$D23 (DEC3)
unnamed: C18.1, U1.P$F2 (P0.01/XL2), X2.1
unnamed: C13.1, U1.P$A18 (DEC2)
unnamed: L2.1, L3.2
unnamed: L2.2, U1.P$B3 (DCC)
unnamed: C10.1, C15.1, C16.1, L3.1, U1.P$B5 (DEC4), U1.P$E24 (DEC6)
unnamed: C17.1, U1.P$D2 (P0.00/XL1), X2.2
unnamed: IC3.1 (SDO), R3.2
unnamed: C5.2, U1.P$C1 (DEC1)
P0.04: U1.P$J1 (P0.04/AIN2)
P0.09: U1.P$L24 (P0.09/NFC1)
P0.13: U1.P$AD8 (P0.13); also elsewhere on the board
P0.14: U1.P$AC9 (P0.14); also elsewhere on the board
P0.19: U1.P$AC15 (P0.19)
P0.20: U1.P$AD16 (P0.20)
P0.21: U1.P$AC17 (P0.21)
P0.22: U1.P$AD18 (P0.22)
P0.23: U1.P$AC19 (P0.23)
P0.24: U1.P$AD20 (P0.24)
P0.25: U1.P$AC21 (P0.25)
P0.26: U1.P$G1 (P0.26)
P0.27: U1.P$H2 (P0.27)
P0.28: U1.P$B11 (P0.28/AIN4)
P0.29: U1.P$A10 (P0.29/AIN5)
P0.30: U1.P$B9 (P0.30/AIN6)
P0.31: U1.P$A8 (P0.31/AIN7)
P1.01: U1.P$Y23 (P1.01); also elsewhere on the board
P1.02: U1.P$W24 (P1.02); also elsewhere on the board
P1.03: U1.P$V23 (P1.03)
P1.04: U1.P$U24 (P1.04)
P1.05: U1.P$T23 (P1.05)
P1.06: U1.P$R24 (P1.06)
P1.07: U1.P$P23 (P1.07)
P1.09: U1.P$R1 (P1.09)
P1.10: U1.P$A20 (P1.10)
P1.11: U1.P$B19 (P1.11)
P1.12: U1.P$B17 (P1.12)
P1.13: U1.P$A16 (P1.13)
P1.14: U1.P$B15 (P1.14)
P1.15: U1.P$A14 (P1.15)
PMIC_INT: IC1.A1 (!INT), U1.P$T2 (P0.11)
RESET: J2.6, TP_RESET.TP, U1.P$AC13 (P0.18/RESET)
SCK: U1.P$A12 (P0.02/AIN0); also elsewhere on the board
SWDCLK: J2.4, TP_SWDCLK.TP, U1.P$AA24 (SWDCLK)
SWDIO: J2.2, TP_SWDIO.TP, U1.P$AC24 (SWDIO)
SWO: TP_SWO.TP, U1.P$AD22 (P1.00)
VBUS: C21.1, C38.2, IC1.A2 (IN), U1.P$AD2 (VBUS); also elsewhere on the board
VREG: C23.2, C24.2, C39.1, IC1.B2 (SYS), IC9.A1 (EN), IC9.A2 (VIN_1), IC9.A3 (VIN_2), TP_VREG.TP

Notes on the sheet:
LiPo Charger
DC/DC
IMU
SWD
DEC1
DEC4_6
DEC3
P0.00/XL1
P0.01/XL2

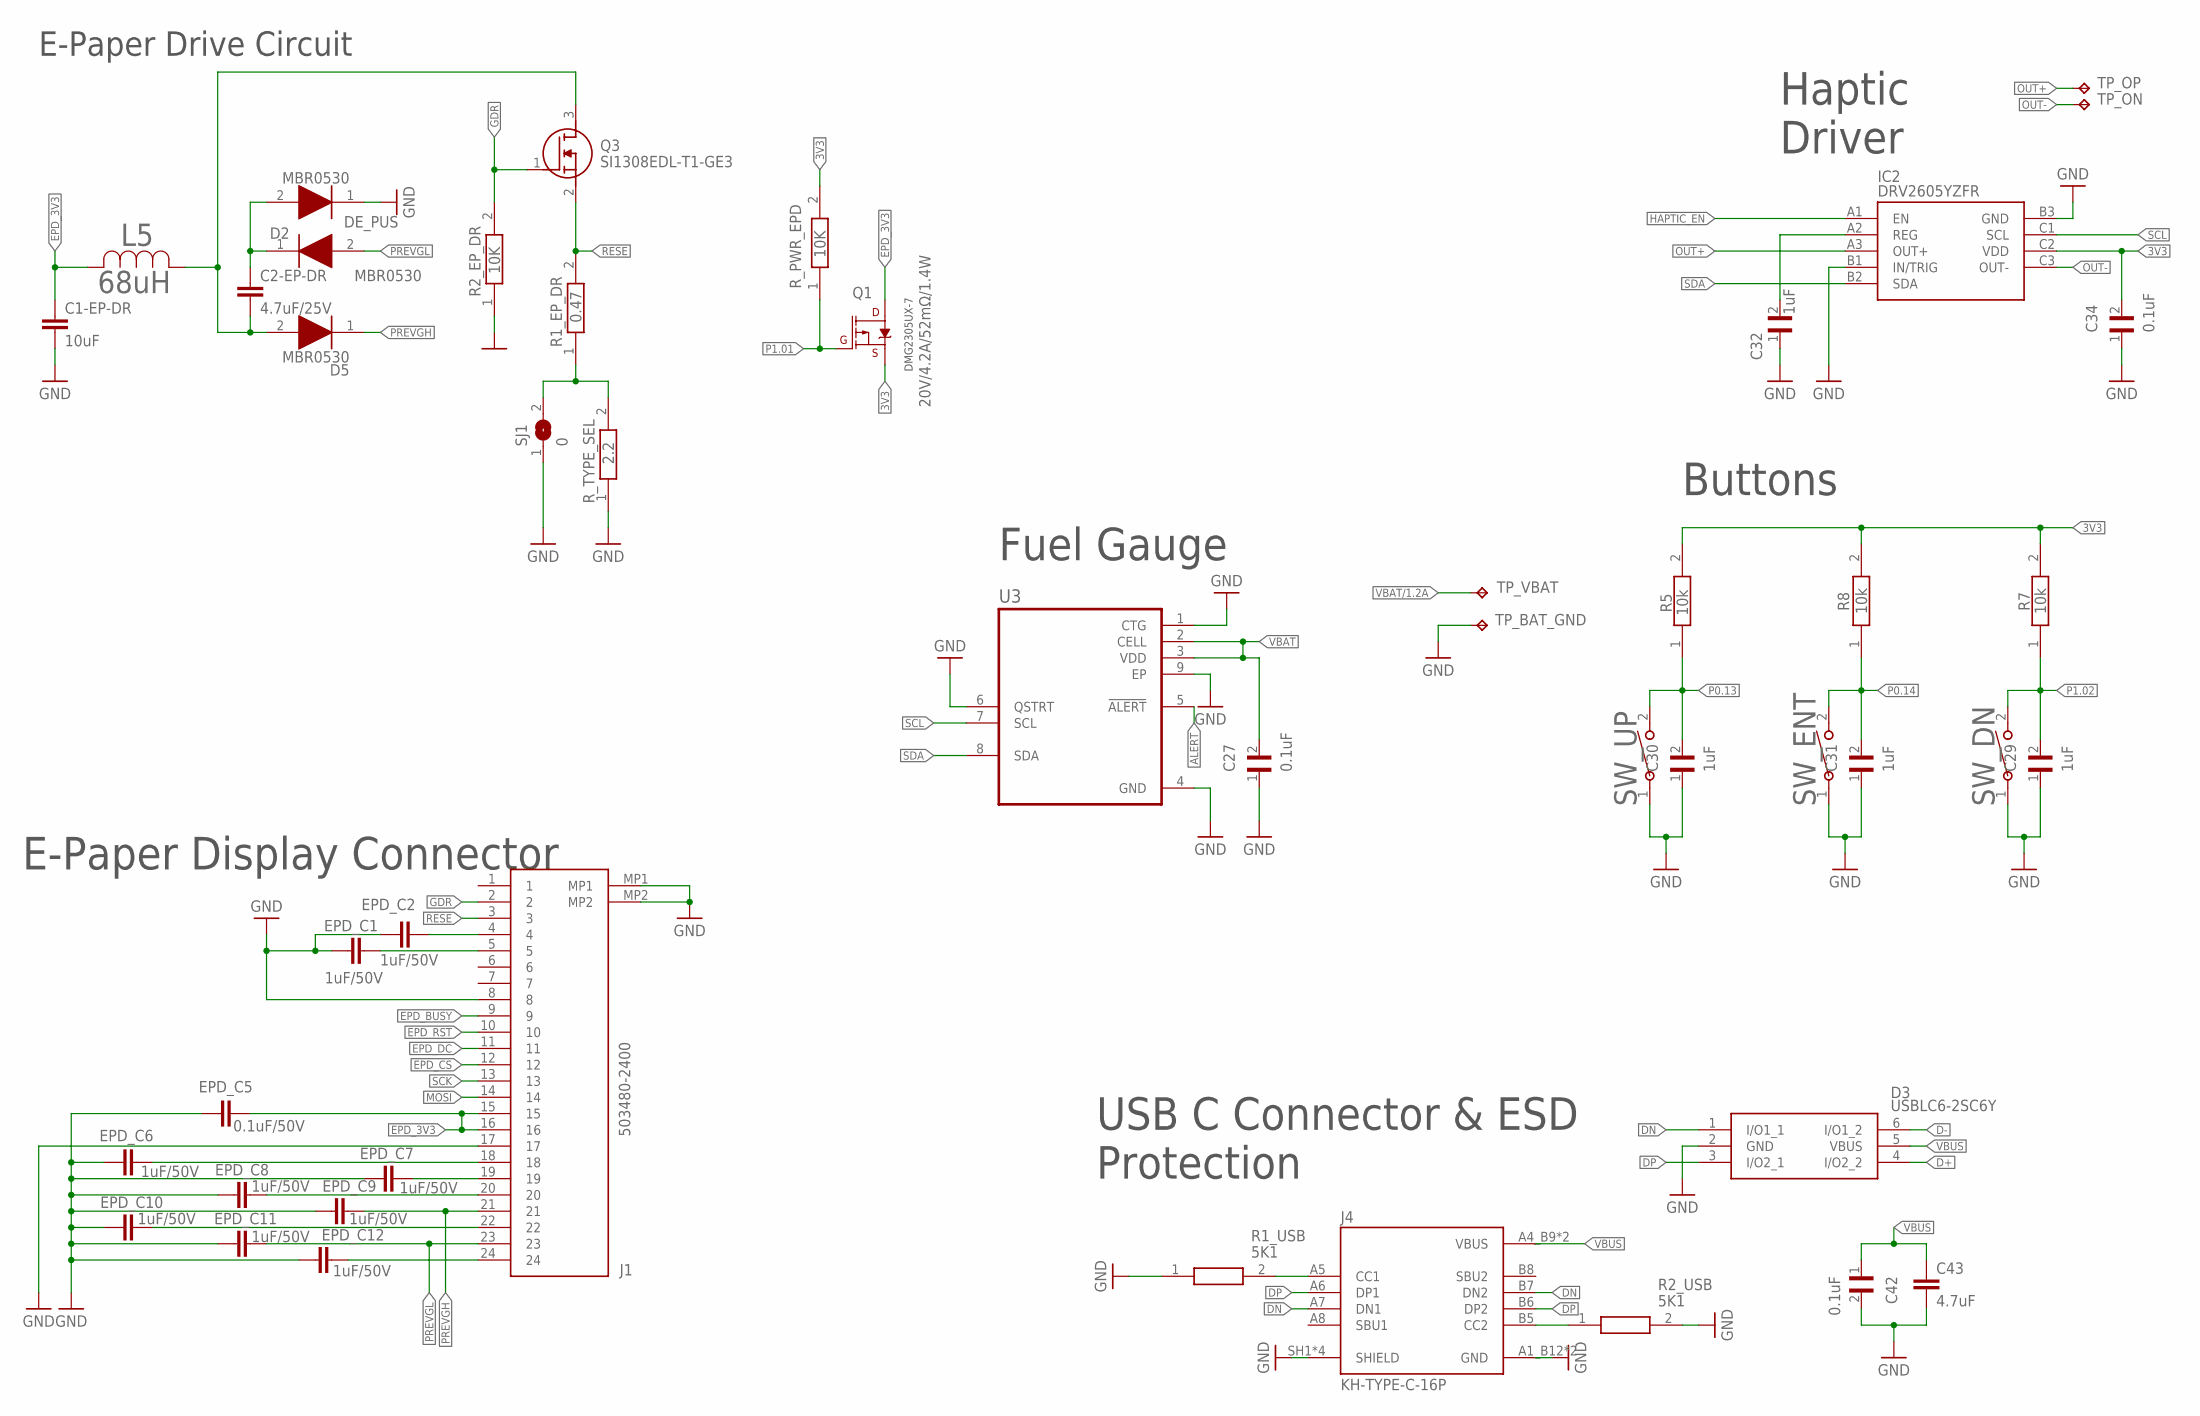
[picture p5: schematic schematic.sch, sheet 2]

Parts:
C1-EP-DR: 10uF; NORDIC_NRF_3_RESC0402_L
C2-EP-DR: 4.7uF/25V; NORDIC_NRF_3_RESC0402_L
C27, C34, C42: 0.1uF; GRM011R60J152KE01L_2_CAPC0201X13N
C29, C30, C31, C32: 1uF; GRM011R60J152KE01L_2_CAPC0201X13N
C43: 4.7uF; NORDIC_NRF_3_RESC0402_L
D2, D5: MBR0530; ESP32_C6_LIBRARY_5_SOD3716X135N
D3: USBLC6-2SC6Y; ESP32_C6_LIBRARY_3_SOT95P280X145-6N
DE_PUS: MBR0530; ESP32_C6_LIBRARY_5_SOD3716X135N
EPD_C1, EPD_C2, EPD_C6, EPD_C7, EPD_C8, EPD_C9, EPD_C10, EPD_C11, EPD_C12: 1uF/50V; NORDIC_NRF_3_RESC0402_L
EPD_C5: 0.1uF/50V; NORDIC_NRF_3_RESC0402_L
IC2: DRV2605YZFR; DRV2605YZFR_BGA9C50P3X3_144X144X62
J1: 503480-2400; 503480-2400_5034802400
J4: KH-TYPE-C-16P; KH-TYPE-C-16P_KINGHELM_KH-TYPE-C-16P
L5: 68uH; ESP32_C6_LIBRARY_2_IND_4828-WE-TPC_WRE
Q1: 20V/4.2A/52mΩ/1.4W; ESP32_C6_LIBRARY_4_ESP32_C6_LIBRARY_4_ESP32_C6_LIBRARY_4_ES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
Q3: SI1308EDL-T1-GE3; ESP32_C6_LIBRARY_6_SOT65P210X110-3N
R1_EP_DR: 0.47; CPF0201D7K68C1_0201
R1_USB, R2_USB: 5K1; CPF0201D7K68C1_0201
R2_EP_DR: 10K; CPF0201D7K68C1_0201
R5, R7, R8: 10k; CPF0201D7K68C1_0201
R_PWR_EPD: 10K; CPF0201D7K68C1_0201
R_TYPE_SEL: 2.2; CPF0201D7K68C1_0201
SJ1: 0; ESP32_C6_LIBRARY_7_JUMPER_SJ
SW_DN: 2025-10-22_07-23-44_LIBRARY_EVP-AKE31ASW_EVP-AKE3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; 2025-10-22_07-23-44_LIBRARY_SW_EVP-AKE31A_PAN
SW_ENT: 2025-10-22_07-23-44_LIBRARY_EVP-AKE31ASW_EVP-AKE3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; 2025-10-22_07-23-44_LIBRARY_SW_EVP-AKE31A_PAN
SW_UP: 2025-10-22_07-23-44_LIBRARY_EVP-AKE31ASW_EVP-AKE3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; 2025-10-22_07-23-44_LIBRARY_SW_EVP-AKE31A_PAN
TP_BAT_GND: HECTOR_WATCH_1_TPTP20R; HECTOR_WATCH_1_TP20R
TP_ON: HECTOR_WATCH_1_TPTP20R; HECTOR_WATCH_1_TP20R
TP_OP: HECTOR_WATCH_1_TPTP20R; HECTOR_WATCH_1_TP20R
TP_VBAT: HECTOR_WATCH_1_TPTP20R; HECTOR_WATCH_1_TP20R
U3: ESP32_C6_LIBRARY_MAX17048G+T10; ESP32_C6_LIBRARY_SON50P200X200X80-9N

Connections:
3V3: C34.2, IC2.C2 (VDD), Q1.2 (S), R5.2, R7.2, R8.2, R_PWR_EPD.2; also elsewhere on the board
ALERT: U3.5 (!ALERT); also elsewhere on the board
D+: D3.4 (I/O2_2); also elsewhere on the board
D-: D3.6 (I/O1_2); also elsewhere on the board
DN: D3.1 (I/O1_1), J4.A7 (DN1), J4.B7 (DN2)
DP: D3.3 (I/O2_1), J4.A6 (DP1), J4.B6 (DP2)
EPD_3V3: C1-EP-DR.1, EPD_C5.2, J1.15, J1.16, L5.2, Q1.3 (D)
EPD_BUSY: J1.9; also elsewhere on the board
EPD_CS: J1.12; also elsewhere on the board
EPD_DC: J1.11; also elsewhere on the board
EPD_RST: J1.10; also elsewhere on the board
GDR: J1.2, Q3.1 (G), R2_EP_DR.2
GND: C1-EP-DR.2, C27.1, C29.1, C30.1, C31.1, C32.1, C34.1, C42.2, C43.2, D3.2 (GND), DE_PUS.1 (K), EPD_C1.1, EPD_C2.1, EPD_C5.1, EPD_C6.1, EPD_C7.1, EPD_C8.1, EPD_C9.1, EPD_C10.1, EPD_C11.1, EPD_C12.1, IC2.B1 (IN/TRIG), IC2.B3 (GND), J1.8, J1.17, J1.MP1, J1.MP2, J4.A1_B12 (GND), J4.A12_B1 (GND), J4.SH1 (SHIELD), J4.SH2 (SHIELD), J4.SH3 (SHIELD), J4.SH4 (SHIELD), R1_USB.1, R2_EP_DR.1, R2_USB.2, R_TYPE_SEL.1, SJ1.1, SW_DN.1, SW_ENT.1, SW_UP.1, TP_BAT_GND.TP, U3.1 (CTG), U3.4 (GND), U3.6 (QSTRT), U3.9 (EP); also elsewhere on the board
HAPTIC_EN: IC2.A1 (EN); also elsewhere on the board
MOSI: J1.14; also elsewhere on the board
unnamed: R1_EP_DR.1, R_TYPE_SEL.2, SJ1.2
unnamed: C32.2, IC2.A2 (REG)
unnamed: C2-EP-DR.1, D2.1 (K), DE_PUS.2 (A)
unnamed: C2-EP-DR.2, D5.2 (A), L5.1, Q3.3 (D)
unnamed: EPD_C2.2, J1.4
unnamed: EPD_C1.2, J1.5
unnamed: J4.B5 (CC2), R2_USB.1
unnamed: EPD_C7.2, J1.19
unnamed: EPD_C12.2, J1.24
unnamed: EPD_C6.2, J1.18
unnamed: EPD_C8.2, J1.20
unnamed: EPD_C10.2, J1.22
unnamed: J4.A5 (CC1), R1_USB.2
OUT+: IC2.A3 (OUT+), TP_OP.TP
OUT-: IC2.C3 (OUT-), TP_ON.TP
P0.13: C30.2, R5.1, SW_UP.2; also elsewhere on the board
P0.14: C31.2, R8.1, SW_ENT.2; also elsewhere on the board
P1.01: Q1.1 (G), R_PWR_EPD.1; also elsewhere on the board
P1.02: C29.2, R7.1, SW_DN.2; also elsewhere on the board
PREVGH: D5.1 (K), EPD_C9.2, J1.21
PREVGL: D2.2 (A), EPD_C11.2, J1.23
RESE: J1.3, Q3.2 (S), R1_EP_DR.2
SCK: J1.13; also elsewhere on the board
VBUS: C42.1, C43.1, D3.5 (VBUS), J4.A4_B9 (VBUS), J4.A9_B4 (VBUS); also elsewhere on the board

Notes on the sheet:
E-Paper Drive Circuit
DMG2305UX-7
Haptic Driver
Fuel Gauge
Buttons
USB C Connector & ESD Protection
E-Paper Display Connector

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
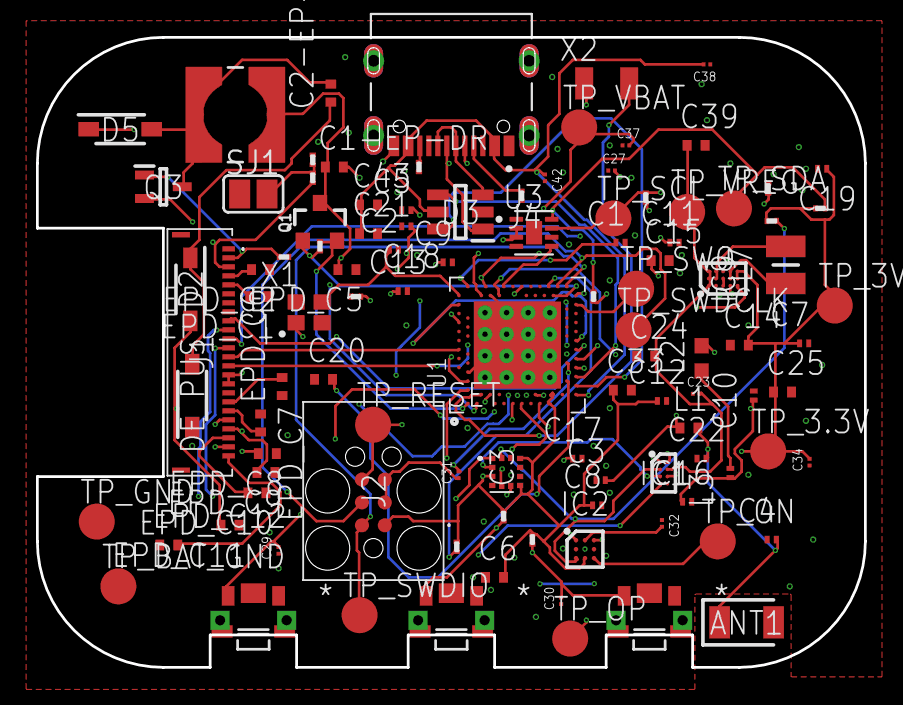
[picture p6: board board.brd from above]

Board: 4 copper layers, 46.0 x 35.0 mm, 105 parts (0 on the bottom side), 70 nets.

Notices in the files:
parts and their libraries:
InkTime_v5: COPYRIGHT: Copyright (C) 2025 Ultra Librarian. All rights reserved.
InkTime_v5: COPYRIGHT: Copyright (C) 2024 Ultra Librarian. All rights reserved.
